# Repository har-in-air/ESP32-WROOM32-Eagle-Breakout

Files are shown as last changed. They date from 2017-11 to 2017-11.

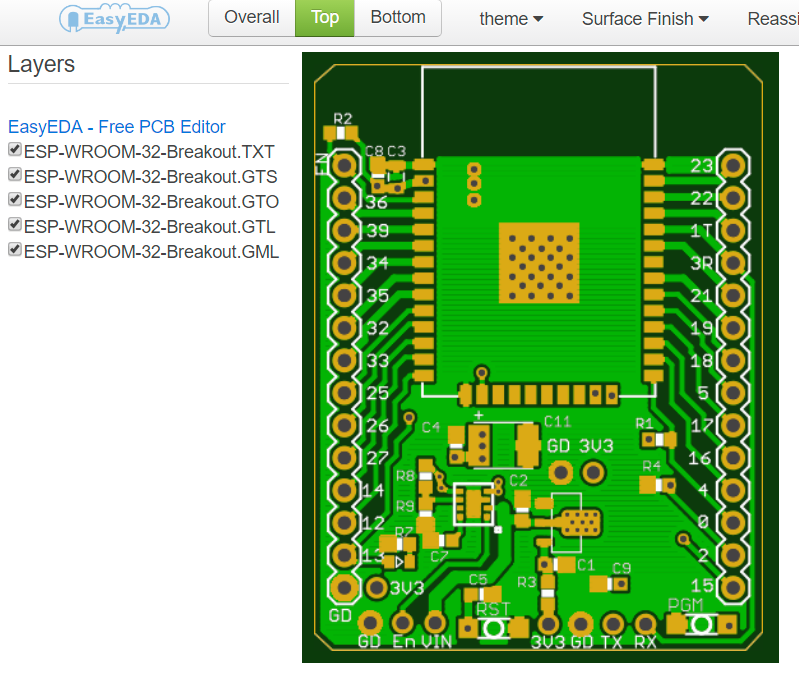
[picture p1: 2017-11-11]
top.png

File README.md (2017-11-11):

# ESP32-WROOM32-Eagle-Breakout

A breadboard compatible Eagle breakout board for Espressif's ESP32 module ESP-WROOM-32. 

## Credits
I started with the schematic and layout from 
https://github.com/StudioSophisti/ESP-WROOM-32-Eagle-Breakout
and heavily modified it for my purposes. 

## Features
Pinout on the board corresponds to the WROOM-32 module pinout. This ensures shortest path connections with minimum vias.

Adequate power planes and heatsinking for the WROOM-32 module.  

Multiple decoupling capacitors, including optional large low ESR tantalum (e.g. 330uF 6.3V). This will prevent brownout resets from current spikes when running off power supplies with limited current capacity.

Two voltage regulator options : 
1. LDO regulator - HT7833 / HT7333 in SOT89 package.  HT7833 has a higher max current and higher dropout voltage - ok for USB power. HT7333 has lower max current and lower dropout voltage - ok for Lipoly battery power if not running at max clock frequency or not using the radio.
2. Switching regulator (TPS82140) when efficiency is important and the source voltage can be up to 17V

LED on IO13. Pull-down resistor on IO2. Pull-up resistor on IO0.

No USB-UART chip on-board, to minimize deep sleep power consumption.

For testing/programming, if your USB-UART dongle 3.3V pin can provide enough power, short R3 and do not populate the regulator ICs. Otherwise, use one of the regulator options, provide power via VIN and leave R3 unpopulated.

The buttons, programming interface and regulator input pins have been placed on the edge to facilitate using the board in a case.

Pinout silkscreen on top AND bottom.

Board dimensions : ~ 36mm x 46mm

Resistors are 0603 package. Capacitors are 0603 except for C6 (tantalum C, e.g. 330uF 4V), C11 (tantalum B, can fit 220uF 4V). You can find suitable capacitors (0603 X5R, X7R) on Aliexpress and Ebay e.g. https://mcigicm.aliexpress.com/store/506373?spm=2114.10010108.0.0.15e3fdeesSP1Dd

Pcbway.com is an inexpensive pcb prototyping service I've used before : 10 PCBs  (2-layer, < 100mm x 100mm ) for US$5 + shipping. Great quality, but in my experience, it takes about 4-5 weeks from order to delivery with their cheapest shipping option.

## Assembly notes

This layout is meant for manual assembly. I have placed vias in pads for shortest path to the power planes.  The TPS82140 will have 
to be reflowed with the home-brew method of your choice - e.g. electric skillet. There's no need to risk reflowing the WROOM-32, just put thermal paste on the ground pad before hand-soldering the module pins.

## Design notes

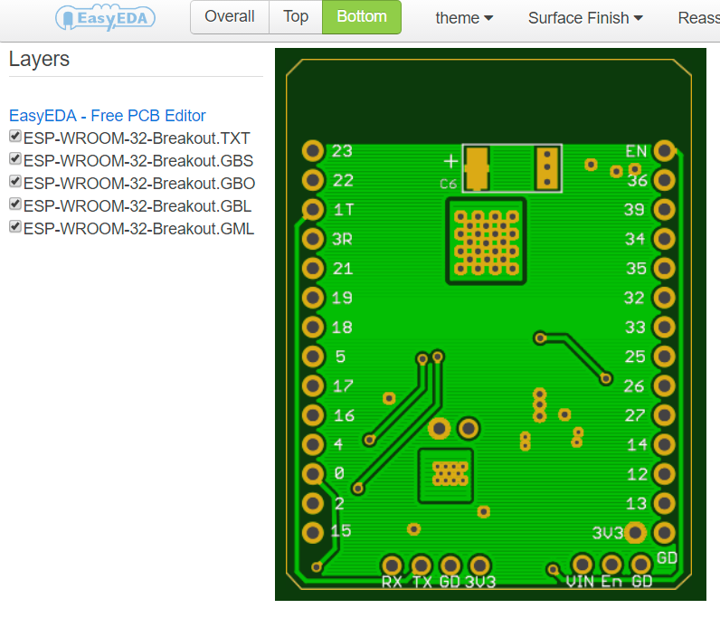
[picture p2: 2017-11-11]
bottom.png

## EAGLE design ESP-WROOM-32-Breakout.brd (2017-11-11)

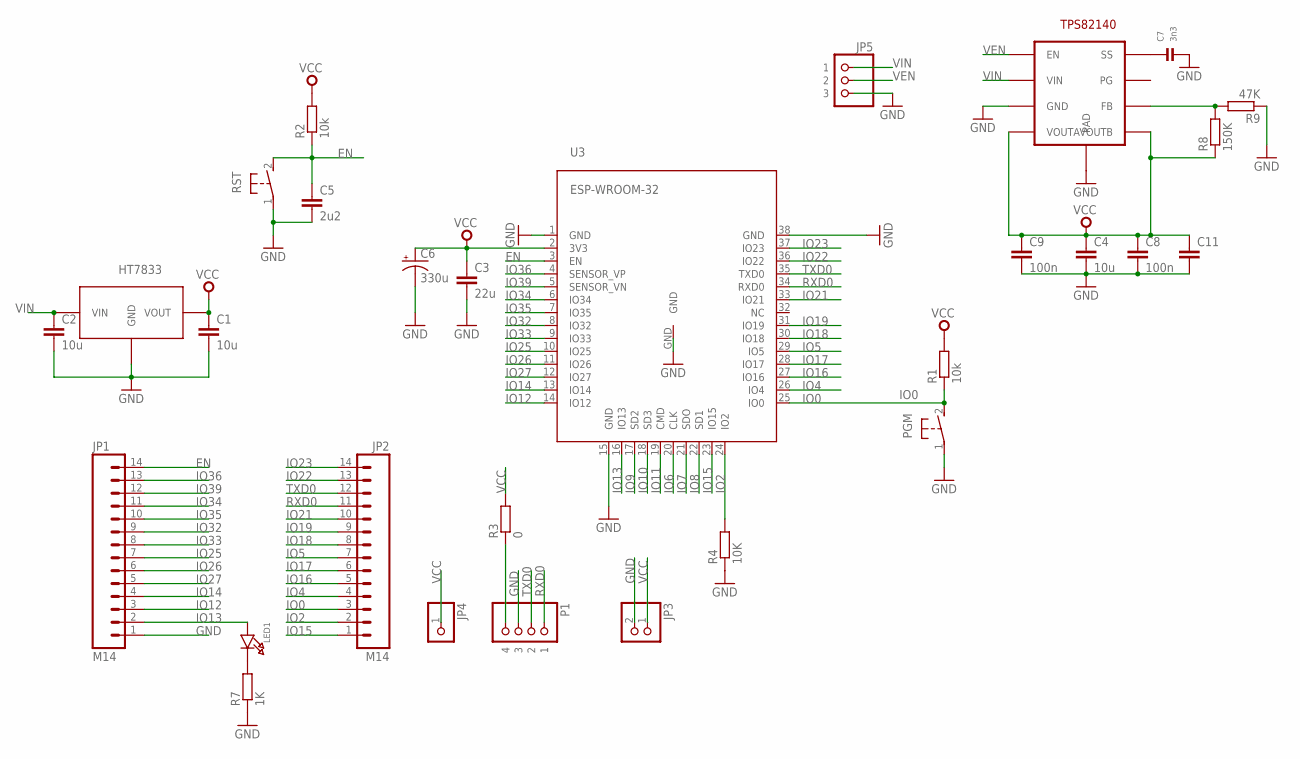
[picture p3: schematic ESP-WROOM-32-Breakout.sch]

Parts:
C1, C2, C4: 10u; C0603
C3: 22u; 0805
C5: 2u2; C0603
C6: 330u; VISHAY_C
C7: 3n3; 0603
C8, C9: 100n; C0603
C11: CAPSMD; GRM43D
JP1, JP2: M14; 1X14
JP3: HEADER-1X2ROUND; 1X02_ROUND
JP4: HEADER-1X1ROUND; 1X01_ROUND
JP5: HEADER-1X3ROUND; 1X03_ROUND
LED1: LED0603; CHIPLED_0603
P1: HEADER-1X4ROUND; 1X04_ROUND
PGM: DTSM-3
R1, R2: 10k; R0603
R3: 0; R0603
R4: 10K; R0603
R7: 1K; R0603
R8: 150K; R0603
R9: 47K; R0603
RST: DTSM-3
U3: ESP-WROOM-32
U$1: HT7833; SOT89
U$2: TPS82140

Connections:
EN: C5.1, JP1.14, R2.1, RST.2, U3.3 (EN)
GND: C1.2, C2.2, C3.2, C4.2, C5.2, C6.-, C7.2, C8.2, C9.2, C11.C (2), JP1.1, JP3.2, JP5.3, P1.3, PGM.1, R4.1, R7.1, R9.1, RST.1, U3.1 (GND), U3.15 (GND), U3.38 (GND), U3.GND, U$1.GND, U$2.P$3 (GND), U$2.P$9 (PAD)
IO0: JP2.3, PGM.2, R1.1, U3.25 (IO0)
IO2: JP2.2, R4.2, U3.24 (IO2)
IO4: JP2.4, U3.26 (IO4)
IO5: JP2.7, U3.29 (IO5)
IO6: U3.20 (CLK)
IO7: U3.21 (SDO)
IO8: U3.22 (SD1)
IO9: U3.17 (SD2)
IO10: U3.18 (SD3)
IO11: U3.19 (CMD)
IO12: JP1.3, U3.14 (IO12)
IO13: JP1.2, LED1.A, U3.16 (IO13)
IO14: JP1.4, U3.13 (IO14)
IO15: JP2.1, U3.23 (IO15)
IO16: JP2.5, U3.27 (IO16)
IO17: JP2.6, U3.28 (IO17)
IO18: JP2.8, U3.30 (IO18)
IO19: JP2.9, U3.31 (IO19)
IO21: JP2.10, U3.33 (IO21)
IO22: JP2.13, U3.36 (IO22)
IO23: JP2.14, U3.37 (IO23)
IO25: JP1.7, U3.10 (IO25)
IO26: JP1.6, U3.11 (IO26)
IO27: JP1.5, U3.12 (IO27)
IO32: JP1.9, U3.8 (IO32)
IO33: JP1.8, U3.9 (IO33)
IO34: JP1.11, U3.6 (IO34)
IO35: JP1.10, U3.7 (IO35)
IO36: JP1.13, U3.4 (SENSOR_VP)
IO39: JP1.12, U3.5 (SENSOR_VN)
unnamed: P1.4, R3.1
unnamed: LED1.C, R7.2
unnamed: C7.1, U$2.P$8 (SS)
unnamed: R8.2, R9.2, U$2.P$6 (FB)
RXD0: JP2.11, P1.1, U3.34 (RXD0)
TXD0: JP2.12, P1.2, U3.35 (TXD0)
VCC: C1.1, C3.1, C4.1, C6.+, C8.1, C9.1, C11.A (1), JP3.1, JP4.1, R1.2, R2.2, R3.2, R8.1, U3.2 (3V3), U$1.VOUT, U$2.P$4 (VOUTA), U$2.P$5 (VOUTB)
VEN: JP5.2, U$2.P$1 (EN)
VIN: C2.1, JP5.1, U$1.VIN, U$2.P$2 (VIN)

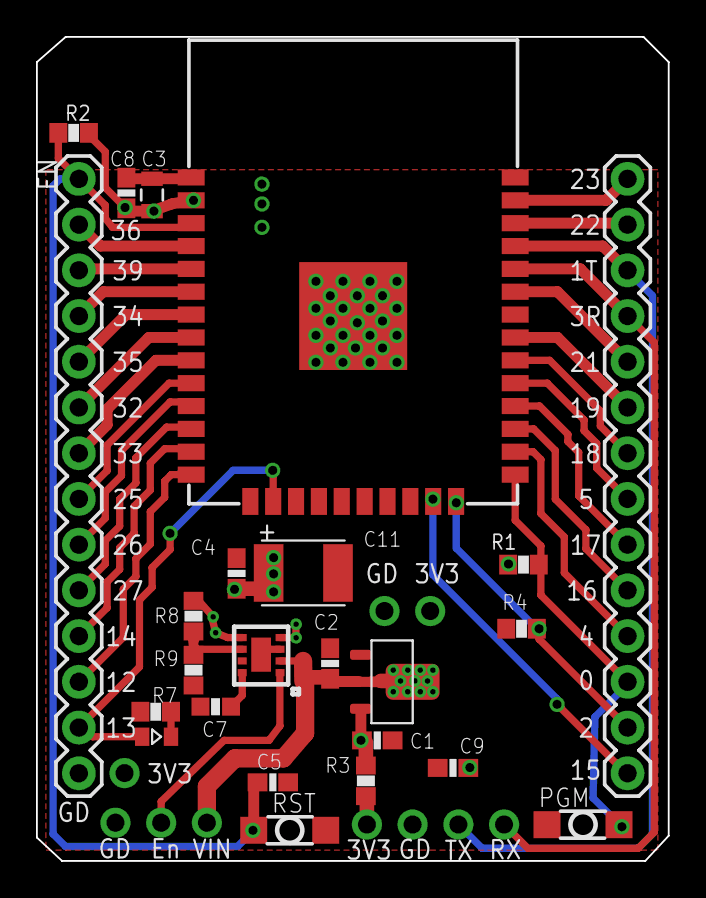
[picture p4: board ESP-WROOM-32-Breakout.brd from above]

Board: 2 copper layers, 35.1 x 45.8 mm, 29 parts (1 on the bottom side), 35 nets.

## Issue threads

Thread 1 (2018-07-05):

TPS82140 output voltage

carbonadam, 2018-07-05:
What voltage is the Switching regulator meant to be outputting?

carbonadam, 2018-07-05:
I like the TPS82140.  I was thinking of running a 3s battery into it and then hopefully thats all I would need for the power side or do I need both the TPS and HT7833?  I just cant quite figure out how that TPS is being enabled otherwise.

har-in-air, 2018-07-05:
Just the tps circuit. You can't have both regulators on the board. 

Sent from Yahoo Mail on Android

  On Thu, 5 Jul 2018 at 19:31, Adam<notifications@github.com> wrote:
I like the TPS82140. I was thinking of running a 3s battery into it and then hopefully thats all I would need for the power side or do I need both the TPS and HT7833? I just cant quite figure out how that TPS is being enabled otherwise.

—
You are receiving this because you commented.

Reply to this email directly, view it on GitHub, or mute the thread.

noblerabbit, 2018-11-16:
Hi, Did you measure deep sleep current?

har-in-air, 2018-11-17:
Sorry, no...

Sent from Yahoo Mail on Android

  On Sat, 17 Nov 2018 at 1:36, noblerabbit<notifications@github.com> wrote:
Hi, Did you measure deep sleep current?

—
You are receiving this because you commented.
Reply to this email directly, view it on GitHub, or mute the thread.

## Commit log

2017-10-10 pinout silkscreen on bottom, wider traces
    [ESP-WROOM-32-Breakout.brd]
2017-11-11 Add files via upload
    moved led to pin 13, changed cap package C11 (now can accomodate tantalum B size e.g. 220uf 4V), remove thermals on some footprints for contiguous ground plane
    [ESP-WROOM-32-Breakout.brd, ESP-WROOM-32-Breakout.sch]

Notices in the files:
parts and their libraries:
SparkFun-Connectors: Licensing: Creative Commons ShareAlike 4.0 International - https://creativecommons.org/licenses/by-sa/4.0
